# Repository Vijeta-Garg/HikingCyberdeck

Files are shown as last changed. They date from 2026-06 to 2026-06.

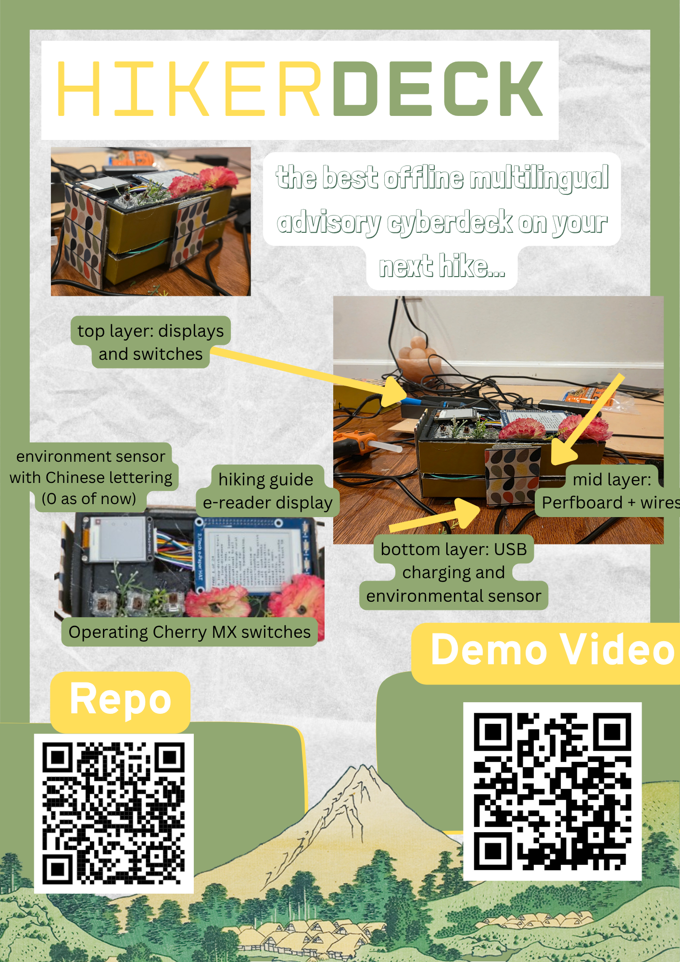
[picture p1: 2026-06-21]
HikerDeck Zine.png

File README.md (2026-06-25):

# HikerDeck

# My inspiration: 
My Instagram feed inspired me to make a cyberdeck, offline computers housed in cute compartments one could access offline. My sister had her birthday just a few weeks ago, so I wanted to gift her a cyberdeck she'd love. User needs: she is into hiking, reading, and learning new languages (currently Chinese). So I made a multilingual e-reading environment-sensing cyberdeck that would be useful on a hike. For example, it can load up a "hiking survival guide" on an offline e-reader and also tell you the altitude you are at in the hike in Chinese numerals. 



# What does the project do?
The project is a dual-display cyberdeck optimized for hiking. It is an offline "mini computer" which can scroll through files such as a hiking survival guide. At the same time, on another display it can display the current pressure and altitude a hiker is at in Chinese lettering. The cyberdeck itself is controlled by 3 CherryMX switches and is housed inside a sunglass case! 
In summary, the main features include:
- Large screen displays hiking survival text uploaded by computer
- Small screen displays environmental data in Chinese lettering
- You can control back/forward pages and turning the small display on and off via 3 Cherry MX keys 

# Schematic:
Please note! The hikerdeck is currently perfboarded not PCBed! The entire wiring is contained inside the casing and once spread out it looks like this:


# Firmware
The firmware adds on top of pre-existing sensor and display libraries (most notably gc and framebuffer) to display sensor values (like altitude) onto the small display. Using a custom-made Chinese bitmap font library, the firmware prints to the smaller display in Chinese lettering. At the same time, it also coordinates SPI activation between both the large and small displays which are wired onto the same SPI bus. The firware also takes the external buttons as inputs for when to switch display or when to switch pages on the larger display. The firware additionally calculates how many pages of hiking survival guide text there are on the large display and renders them onto the large display in an appropriate manner (without breaking up too much text or going off the page). 
Usage of each file is as following:
+ Pico_ePaper_2_7_V2.py --> library for the ePaper 2.7in V2 display (pre-existing) 
+ bmp280.py --> library for environment sensor (pre-existing) 
+ bmpWithSmallDisp.py --> module I made (which includes some pre-existing library code for 1.54'' display) which displays environmental stats in
+ Chinese lettering on the small display 
+ ChineseNum.py --> bitmap library I refer to in bmpWithSmallDisp.py helps me map characters onto small display 
+ main.py --> accepts button input, calculates and renders text info for the large display, controls SPI activation/switching, imports bmpWithSmallDisp to also switch to small display rendering 

# Layout:
I drew a small diagram to help you understand where everything fits inside the casing! 


# Casing:
Currently not 3D printed yet, but the CAD files are ready and I am using a cardboard case right now! 


This is a cut open view of the whole case so you can see that there is a "top layer" where the displays are housed and a "bottom layer" with space for wiring and pico w. 



^This is how the entire case would look assembled together, probably with screws to hold top and bottom layers in place. CAD folder has a 3D design version of the entire casing together and then parts of the casing which may be easier to CAD.

# How to build this?
1. Import firmware to VS code and connect pico w to VS code via pico extension on VS code 
3. Plug in the small display using the SPI1 pins on the pico w pinout (some specified in firmware) 
4. Plug in sensor via 12C pins on BMPE-280 sensor (refer to firmware for definitions!) 
5. Run the small display with sensor script and the firmware should both print environment data in terminal and show chinese version of that on small display (imports custom Chinese font library, framebuffer display etc etc) 
6. Plug in large display and wire up the 3 Cherry MX pins as well. Import the longDistanceTrails.txt file so that it can be rendered onto the large display! 
7. Run the large display script (which imports the small display script and manages all SPI activation etc)
8. CAD casing from files and then screw the casing together
9. Fit all of the wiring inside the casing ! 

# How does it all fit together? 
The sunglass case has different "layers": 
The top layer is the two displays which live on the lid 
Below that, there are 3 mounted CherryMX switches and a port to connect to the pico underneath. 
And on the very bottom under the switches there's the perfboard where the raspberry pico w, battery, and environment sensor live. 



# BOM (proper formatting in bom.csv of the repo) 


**here is the link to my demo video!:** https://youtu.be/0BxvbPZM9zg

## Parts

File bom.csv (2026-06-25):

SR. No | Items | Quantity | Unit Price | Total Price | URL
1 | Raspberry Pico W | 1 | 6.00 | 6.00 | https://www.digikey.com/en/products/detail/raspberry-pi/SC0918/16608263
2 | E-paper Display Waveshare 2.7in Version 2.2 + 8 Pin Header | 1 | 18.95 | 18.95 | https://amazon.com
3 | E-paper Display Waveshare 1.54in Version 1.2 + 8 Pin Header | 1 | 27.99 | 27.99 | https://www.amazon.com/2-7inch-HAT-Resolution-Electronic-Communicating/dp/B075FQKSZ9/ref=sr_1
4 | Sunglass case | 1 | 7.99 | 7.99 | self sourced
5 | Perfboard 2.36inx1.57in | 1 | 1.89 | 1.89 | https://www.amazon.com/QSYZAIL-Perfboard-Compatible-Soldering-Protoboard/dp/B0G4QTPVZ8/ref=sr
7 | GY-BMPE280 Sensor | 1 | 6.99 | 6.99 | https://amazon.com
8 | CherryMX switches | 3 | 0.44 | 1.33 | https://www.amazon.com/Cherry-Mechanical-Keyboard-Switches-Noticeable/dp/B0FYR9Z777/ref=sr_1

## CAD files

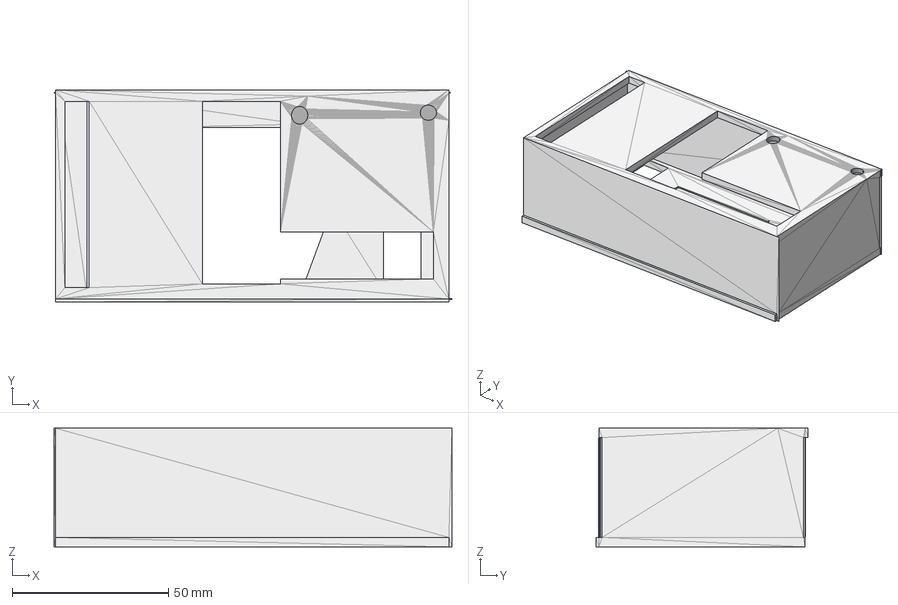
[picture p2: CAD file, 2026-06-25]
CAD/WholeCasingRedone.step
127.5 x 68.0 x 38.0 mm

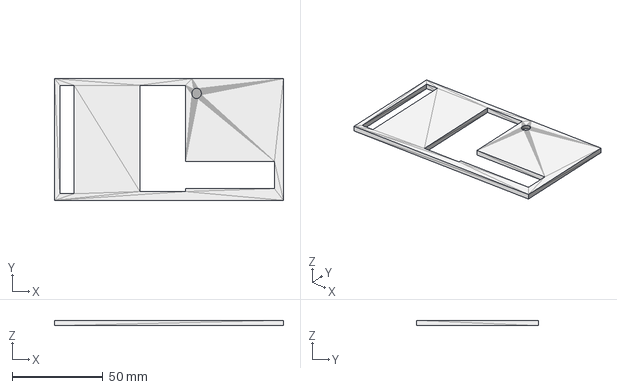
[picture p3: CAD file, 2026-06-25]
CAD/TopLayerAgain.step
126.0 x 67.0 x 3.00 mm

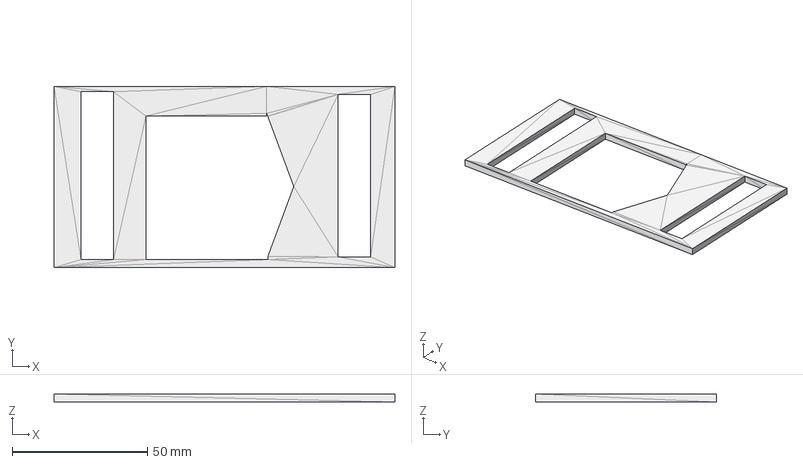
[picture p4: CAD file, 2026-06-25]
CAD/BottomLayer.step
126.0 x 67.0 x 3.00 mm

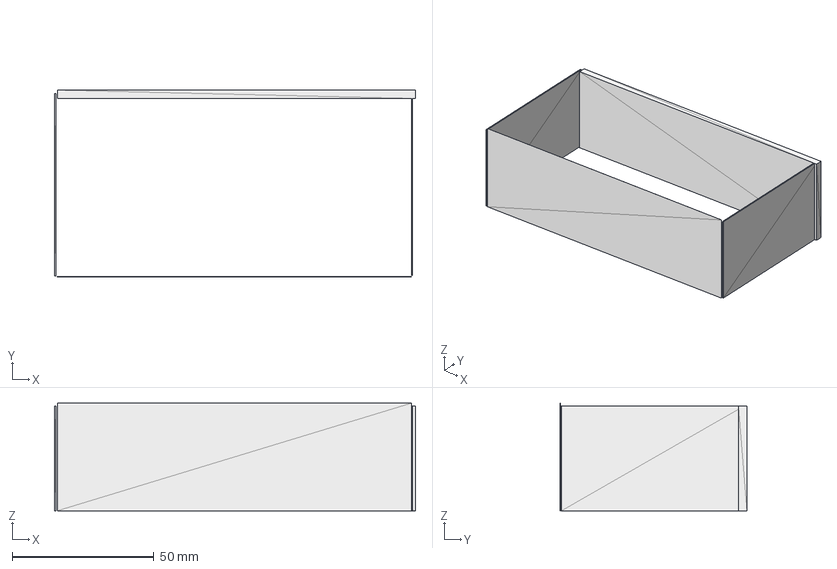
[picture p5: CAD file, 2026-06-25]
CAD/BorderCasing.step
127.5 x 66.0 x 38.0 mm

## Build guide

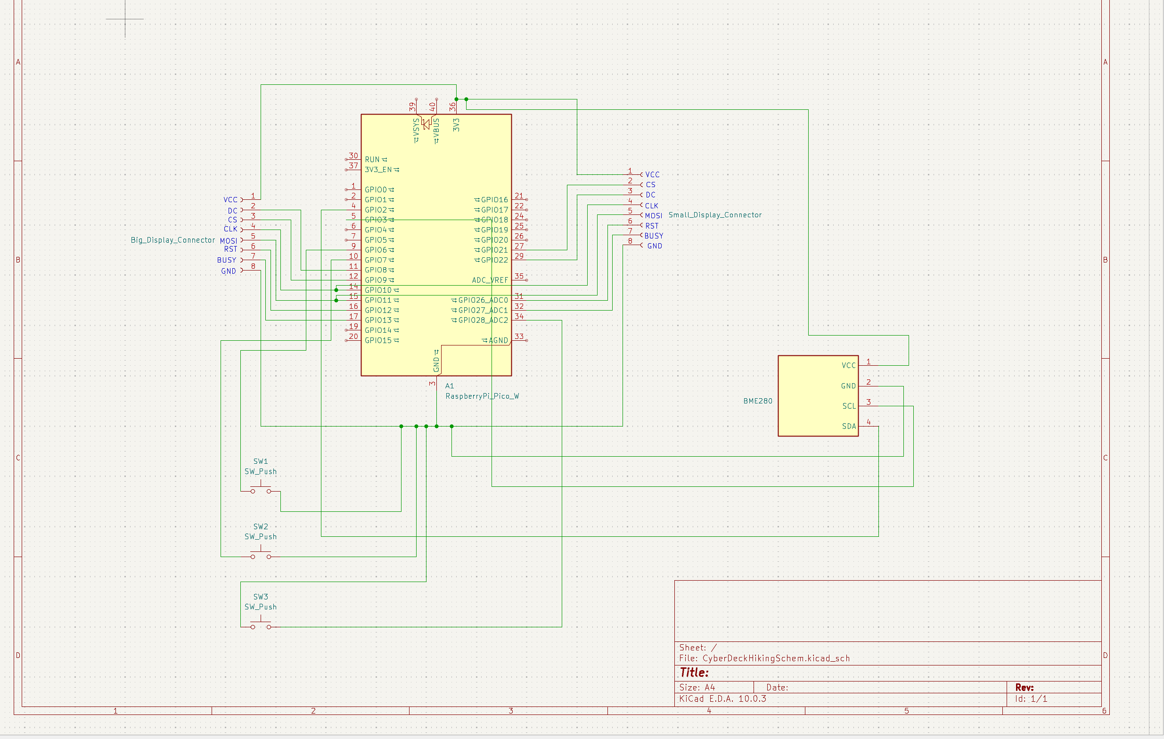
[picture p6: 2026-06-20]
wiringDiagram.png

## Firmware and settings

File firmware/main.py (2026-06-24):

import time
from machine import I2C, Pin, Timer, SPI
import framebuf
import gc 
import bmp280
from chineseNum import CHINESE_NUM_FONTS

# saving the following just to interact with ampy later on if I need to 
# $env:PATH += ";$env:USERPROFILE\AppData\Local\Packages\PythonSoftwareFoundation.Python.3.12_qbz5n2kfra8p0\LocalCache\local-packages\Python312\Scripts"
my_spi_bus = SPI(1, baudrate=2000000, polarity=0, phase=0, sck=Pin(10), mosi=Pin(11))

# muting small disp
cs_small = Pin(21, Pin.OUT, value=1)

import Pico_ePaper_2_7_V2
from bmpWithSmallDisp import EPD_1Inch54_3Color, draw_hybrid_text, num_to_chinese_digits

#  I2C Sensor config
i2c = I2C(1, sda=Pin(2), scl=Pin(3), freq=100000)
bmp = bmp280.BMP280(i2c)
bmp.oversample(bmp280.BMP280_OS_HIGH)
bmp.use_case(bmp280.BMP280_CASE_WEATHER)

EPD_WIDTH_SMALL  = 200
EPD_HEIGHT_SMALL = 200
BUFFER_SIZE_SMALL = 5000 

active_display_mode = 0 
display_mode_changed = False
page_needs_update = False  
current_page = 0 
total_pages = 0              
CHARS_PER_LINE = 21         
LINES_PER_PAGE = 19         


last_sensor_update_time = 0

# Instantiating screens 
epd_large = Pico_ePaper_2_7_V2.EPD_2in7_V2()
epd_small = EPD_1Inch54_3Color(my_spi_bus)
gc.collect()


def stream_words_from_file(filename="longDistanceTrails.txt"):
    try:
        with open(filename, "r") as f:
            buffer = ""
            while True:
                chunk = f.read(64)
                if not chunk:
                    if buffer:
                        yield buffer
                    break
                buffer += chunk
                words = buffer.split()
                if not chunk.endswith((" ", "\n", "\r", "\t")):
                    buffer = words.pop() if words else ""
                else:
                    buffer = ""
                for word in words:
                    yield word
    except OSError:
        print("File not found!")

def get_page_content(target_page_num):
    current_line = ""
    current_page_lines = []
    page_counter = 0
    gc.collect()
    for word in stream_words_from_file():
        if len(current_line) + len(word) + (1 if current_line else 0) <= CHARS_PER_LINE:
            current_line += (" " if current_line else "") + word
        else:
            if current_line:
                current_page_lines.append(current_line)
            current_line = word
            if len(current_page_lines) == LINES_PER_PAGE:
                if page_counter == target_page_num:
                    return "\n".join(current_page_lines)
                page_counter += 1
                current_page_lines = []
                gc.collect()
    if current_line:
        current_page_lines.append(current_line)
    if current_page_lines and page_counter == target_page_num:
        return "\n".join(current_page_lines)
    return "--- End of Document ---"

def precalculate_total_pages():
    global total_pages
    current_line = ""
    line_count = 0
    page_count = 0
    has_words = False
    for word in stream_words_from_file():
        has_words = True
        if len(current_line) + len(word) + (1 if current_line else 0) <= CHARS_PER_LINE:
            current_line += (" " if current_line else "") + word
        else:
            line_count += 1
            current_line = word
            if line_count == LINES_PER_PAGE:
                page_count += 1
                line_count = 0
    if current_line:
        line_count += 1
    if line_count > 0 or (page_count == 0 and not has_words):
        page_count += 1
    total_pages = page_count
    print(f"File scanned! Total Pages: {total_pages}")

precalculate_total_pages()

#page handles (buttons!)
def next_page_handler(pin):
    global current_page, page_needs_update
    if active_display_mode == 0 and not page_needs_update:
        if current_page + 1 < total_pages:
            current_page += 1
            page_needs_update = True

def prev_page_handler(pin):
    global current_page, page_needs_update
    if active_display_mode == 0 and not page_needs_update:
        if current_page > 0:
            current_page -= 1
            page_needs_update = True

def toggle_display_handler(pin):
    global active_display_mode, display_mode_changed
    if not display_mode_changed:
        active_display_mode = 1 if active_display_mode == 0 else 0
        display_mode_changed = True

key_next = Pin(7, Pin.IN, Pin.PULL_UP)
key_next.irq(trigger=Pin.IRQ_FALLING, handler=next_page_handler)

key_prev = Pin(6, Pin.IN, Pin.PULL_UP)
key_prev.irq(trigger=Pin.IRQ_FALLING, handler=prev_page_handler)

key_mode = Pin(28, Pin.IN, Pin.PULL_UP)
key_mode.irq(trigger=Pin.IRQ_FALLING, handler=toggle_display_handler)


def render_page(page_num):
    cs_small.value(1) # Ensure small display is completely locked out 
    print(f"Streaming Page {page_num + 1} onto SPI lines...")
    
    epd_large.image1Gray_Portrait.fill(0xff) 
    epd_large.image1Gray_Portrait.text(f"PAGE {page_num + 1} of {total_pages}", 5, 5, epd_large.black)
    epd_large.image1Gray_Portrait.hline(5, 15, 166, epd_large.black)
    
    text_to_draw = get_page_content(page_num)
    lines = text_to_draw.split("\n")
    
    current_y = 22
    for line in lines:
        epd_large.image1Gray_Portrait.text(line, 5, current_y, epd_large.black)
        current_y += 12 
    
    epd_large.clear() 
    time.sleep(0.3) 
    epd_large.display(epd_large.buffer_1Gray_Portrait) 
    gc.collect()

def render_small_sensor_display():
    print("Writing sharp English labels with Chinese Numerals to 1.54in Display...")
    epd_small.hw_init()
    
    black_data = bytearray([0xFF] * BUFFER_SIZE_SMALL)
    
    fb_black = framebuf.FrameBuffer(black_data, EPD_WIDTH_SMALL, EPD_HEIGHT_SMALL, framebuf.MONO_HMSB)
    fb_black.fill(0xFF) 
    
    try:
        raw_pressure = "{:.0f}".format(bmp.pressure)
        print(raw_pressure)
        raw_altitude = "{:.1f}".format(bmp.altitude) 
        print(raw_altitude)
    except Exception:
        raw_pressure = "0"
        raw_altitude = "0"

    chinese_pressure_num = num_to_chinese_digits(raw_pressure)  
    chinese_altitude_num = num_to_chinese_digits(raw_altitude)  
    print(chinese_altitude_num)
    print(chinese_pressure_num)
    
    # rev string
    pressure_output = "".join(reversed(chinese_pressure_num))
    altitude_output = "".join(reversed(chinese_altitude_num))

    draw_hybrid_text(fb_black, pressure_output, 16, 50, 0, scale=1) 
    draw_hybrid_text(fb_black, altitude_output, 16, 110, 0, scale=1)
    
    epd_small.display_frame(black_data)
    epd_small.sleep()
    gc.collect()

render_page(current_page)


while True:
    if display_mode_changed:
        time.sleep(0.4) 
        if active_display_mode == 0:
            print("Switched Mode: Returning to 2.7-inch Book Reader...")
            render_page(current_page)
        else:
            print("Switched Mode: Launching 1.54-inch Sensor Panel...")
            render_small_sensor_display()
            last_sensor_update_time = time.ticks_ms()
        display_mode_changed = False

    # only reader mode 
    if page_needs_update and active_display_mode == 0:
        render_page(current_page)
        time.sleep(0.2) 
        page_needs_update = False  
    current_time = time.ticks_ms()
    
    if active_display_mode == 1:
        if time.ticks_diff(current_time, last_sensor_update_time) > 8000:
            if not display_mode_changed: 
                render_small_sensor_display()
                last_sensor_update_time = time.ticks_ms()
    else:
        if time.ticks_diff(current_time, last_sensor_update_time) > 3000:
            last_sensor_update_time = time.ticks_ms()

    time.sleep(0.01) 

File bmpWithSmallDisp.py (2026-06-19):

import time
import framebuf 
from machine import Pin, SPI, Timer, I2C
import bmp280
import gc

# Pin definitions directly from your schematic
PIN_CS   = 21 
PIN_DC   = 22  
PIN_RST  = 26 
PIN_BUSY = 27  

EPD_WIDTH  = 200
EPD_HEIGHT = 200
BUFFER_SIZE = 5000  # 200x200 / 8 bits

sensor_needs_read = False    

i2c = I2C(1, sda=Pin(2), scl=Pin(3), freq=100000)
bmp = bmp280.BMP280(i2c)
bmp.oversample(bmp280.BMP280_OS_HIGH)
bmp.use_case(bmp280.BMP280_CASE_WEATHER)

gc.collect()

class EPD_1Inch54_3Color:
    def __init__(self):
        self.cs   = Pin(PIN_CS, Pin.OUT, value=1)
        self.dc   = Pin(PIN_DC, Pin.OUT, value=0)
        self.rst  = Pin(PIN_RST, Pin.OUT, value=1)
        self.busy = Pin(PIN_BUSY, Pin.IN, Pin.PULL_DOWN)
        
        # Hardware SPI1 matching your layout
        self.spi = SPI(1, baudrate=2000000, polarity=0, phase=0, sck=Pin(10), mosi=Pin(11))

    def write_cmd(self, cmd):
        self.dc.value(0)
        self.cs.value(0)
        self.spi.write(bytes([cmd]))
        self.cs.value(1)
        
    def write_data(self, value):
        self.dc.value(1)
        self.cs.value(0)
        self.spi.write(bytes([value]))
        self.cs.value(1)
        
    def chkstatus(self):
        while self.busy.value() == 1:
            time.sleep_ms(50)
        
    def reset(self):
        self.rst.value(0)
        time.sleep_ms(200)
        self.rst.value(1)
        time.sleep_ms(200)
        
    def hw_init(self):
        self.reset()
        self.chkstatus()
        self.write_cmd(0x12) # SWRESET
        self.chkstatus()
        
        self.write_cmd(0x01) 
        self.write_data(0xC7)
        self.write_data(0x00)
        self.write_data(0x00)

        # --- FIX HERE: Changed from 0x01 to 0x03 to make text write forwards ---
        self.write_cmd(0x11) 
        self.write_data(0x03) # 0x03 = X increment, Y increment (Standard Orientation)
        
        self.write_cmd(0x44) 
        self.write_data(0x00)
        self.write_data(0x18) 
        
        self.write_cmd(0x45) 
        self.write_data(0xC7)
        self.write_data(0x00)
        self.write_data(0x00)
        self.write_data(0x00)
        
        self.write_cmd(0x3C) 
        self.write_data(0x05)
        
        self.write_cmd(0x18) 
        self.write_data(0x80)
        
        self.write_cmd(0x4E) 
        self.write_data(0x00)
        self.write_cmd(0x4F) 
        self.write_data(0xC7)
        self.write_data(0x00)
        self.chkstatus()
        
    def update(self):
        self.write_cmd(0x22)
        self.write_data(0xF7)
        self.write_cmd(0x20)
        time.sleep(5) 
        self.chkstatus()

    def display_frame(self, black_buffer, red_buffer=None):
        self.write_cmd(0x24)
        for i in range(BUFFER_SIZE):
            self.write_data(black_buffer[i])
            
        self.write_cmd(0x26)
        for i in range(BUFFER_SIZE):
            if red_buffer is not None:
                self.write_data(red_buffer[i])
            else:
                self.write_data(0x00) 
                
        self.update()

    def display_clear(self):
        self.write_cmd(0x24)
        for i in range(BUFFER_SIZE):
            self.write_data(0xFF) 
        self.write_cmd(0x26)
        for i in range(BUFFER_SIZE):
            self.write_data(0x00) 
        self.update()

    def sleep(self):
        self.write_cmd(0x10)
        self.write_data(0x01)
        time.sleep_ms(10)
        

def timer_sensor_cb(t):
    global sensor_needs_read
    sensor_needs_read = True

timer_b = Timer(period=1000, mode=Timer.PERIODIC, callback=timer_sensor_cb)

def senseAlt():
    print("pressure: {}Pa".format(bmp.pressure))
    print("altitude: {}".format(bmp.altitude))

# --- Main Program Execution ---
if __name__ == '__main__':
    print("Initializing Display...")
    epd = EPD_1Inch54_3Color()
    epd.hw_init()
    
    print("Clearing display cleanly...")
    epd.display_clear()
    time.sleep(1)
    
    # FIX: Pre-fill raw memory blocks to match target baseline configurations
    black_data = bytearray([0xFF] * BUFFER_SIZE)
    red_data   = bytearray([0x00] * BUFFER_SIZE)
    
    fb_black = framebuf.FrameBuffer(black_data, EPD_WIDTH, EPD_HEIGHT, framebuf.MONO_HMSB)
    fb_red   = framebuf.FrameBuffer(red_data, EPD_WIDTH, EPD_HEIGHT, framebuf.MONO_HMSB)
    
    fb_black.fill(1) # 1 = White background
    fb_red.fill(0)   # 0 = Transparent/No red background
    
    # Read fresh sensor data before drawing to screen
    try:
        stPss = "pressure: {:.0f}Pa".format(bmp.pressure)
    except Exception:
        stPss = "Sensor Error"

    # Draw Text on the Black Layer
    print("Writing text to memory...")
    # Shifted X position from 80 to 10 so long pressure strings do not clip off-screen
    fb_black.text(stPss, 10, 95, 0) # 0 = Black text
    
    print("Refreshing screen panels properly...")
    epd.display_frame(black_data, red_data)
    
    print("Done! Putting hardware to sleep.")
    epd.sleep()

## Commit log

2026-06-16 Add files via upload
    includes e-paper display wikipedia scrolling capabilities via external buttons and pressure and altitude terminal logging
2026-06-18 Add files via upload
    updated small display + got it working. Paired 1.54in e-paper display with raspberry pico w . modified pre-existing Seengreat lib.
2026-06-19 Add files via upload
    small display now shows BMP sensor values. still need to fix buffer orientation to make sure text is centered + not backwards
    [bmpWithSmallDisp.py]
2026-06-24 Adjust image size in README for schematic
    Updated schematic image dimensions in README.
2026-06-25 Update README with image and assembly note
    Added an image to the README and noted the need for more information on assembly.
2026-06-25 Replace images of casing in README
    Updated images in the README to reflect current casing design.
2026-06-25 Reintroduce assembly details for sunglass case
    Restored the section explaining how the components fit together in the sunglass case.
2026-06-25 Update README to remove BOM and add demo link
    Removed the BOM table and added a link to a demo video.
2026-06-25 Update BOM image in README.md
    Replaced an image in the BOM section of the README.
2026-06-25 Add original source file link to CAD
2026-06-25 Clean up bom.csv formatting and content
    Removed HTML entities and fixed formatting issues in bom.csv.
    [bom.csv]
